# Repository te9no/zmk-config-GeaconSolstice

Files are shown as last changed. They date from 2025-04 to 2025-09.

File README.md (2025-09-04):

# キーボードについて
キーボード名：GeaconSolstice  
[roBa](https://github.com/kumamuk-git/roBa)や、[GRIN One](https://note.com/policium/n/nc7ceb56d11fe)にインスパイアされて設計したGeaconを、さらに発展させたオリジナルキーボードです。

## 謝辞
トラックボールケースはkepeoさんのデータを利用させていただきました。  
[Keyball Trackball Case (Test) by kepeo - Thingiverse](https://www.thingiverse.com/thing:6749719)  
トラックボール基板はkumaさんの設計したデータを利用させていただきました。  
[GitHub - kumamuk-git/roBa](https://github.com/kumamuk-git/roBa)  

## 特徴
・ZMKによる無線接続対応  
・60%分割Grin配列  
・トラックボール、OLED、アナログスティック搭載  

### US配列


### JIS配列


## 販売
たぶん[booth](https://te9no.booth.pm/)で販売  

## ビルドガイド
[here](https://github.com/te9no/zmk-config-GeaconSolstice/blob/main/docs%2Fbuildguide.md)

## ファームウェア
[Github](https://github.com/te9no/zmk-config-GeaconSolstice/tree/main/firmware)  

## 注意事項
リポバッテリーを不適切に取り扱うと発火等の危険性があります。  
接続時の極性の向きや、リード線の短絡、組み立てには十分ご注意下さい。  
またPCBやケースの角、ピンヘッダーなど鋭利な箇所が多数存在していますので、怪我しないようご注意下さい。  
マイコン裏のパッドはバッテリーに接続されてるため、短絡させないようご注意下さい。  
取り扱いの不備により発生した怪我、事故等の責任は負いかねます。

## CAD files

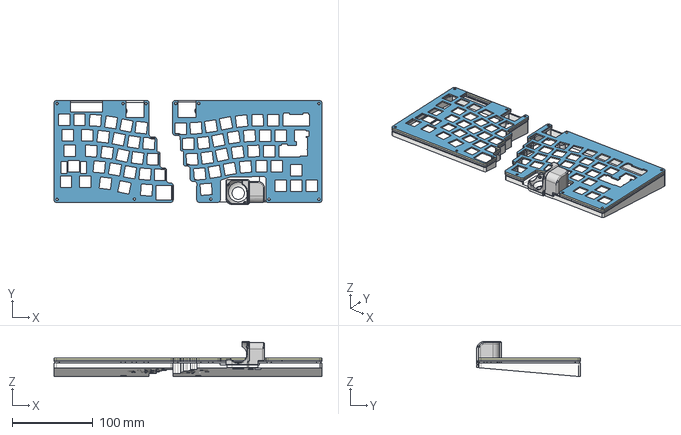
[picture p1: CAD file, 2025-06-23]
case/GeaconSolstice.step
331.8 x 128.9 x 43.7 mm

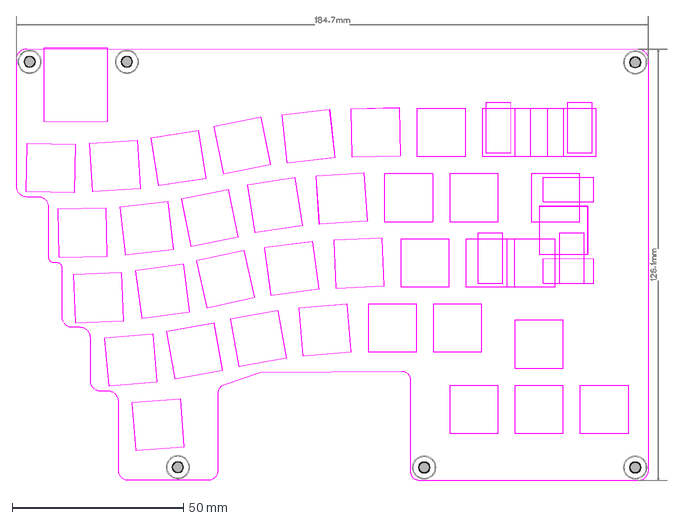
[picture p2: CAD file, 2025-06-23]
case/DXF_GeaconSolstice_R_top_2025-05-07_AutoCAD2007.dxf
190.3 x 135.9 mm

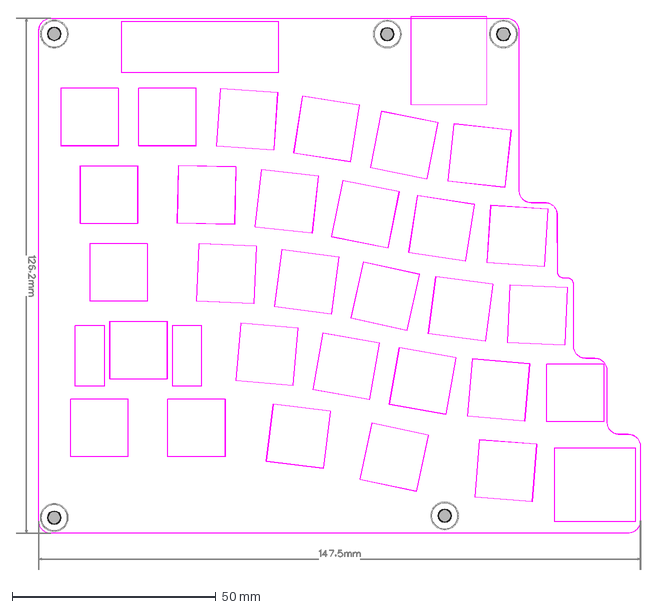
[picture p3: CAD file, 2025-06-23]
case/DXF_GeaconSolstice_L_top_2025-05-07_AutoCAD2007.dxf
153.2 x 135.6 mm

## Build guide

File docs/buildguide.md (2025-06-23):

# 🌞 GeaconSolstice 🌛 ビルドガイド

## 🚀 はじめに
このビルドガイドではGeaconSolsticeの組み立て手順を説明します。組み立ては約1-2時間程度で完了します。

## 📋 目次
1. [部品の確認](#部品確認)
2. [組み立て手順](#組み立て手順)
3. [ファームウェアの書き込み](#ファームウェアの書き込み)
4. [キーボードの使い方](#キーボードの使い方)

## 📦 部品確認
### 📥 付属品
|名前|数|備考|
|:-|:-|:-|
|メインPCB（右）|x1| |
|メインPCB（左）|x1| |
|Seeed Studio XIAO nRF52840|x2|メインPCBに取付済み|
|PMW3610用PCB|x1|メインPCBに取付済み|
|L字ピンヘッダー|x1|メインPCBに取付済み|
|バッテリー用ケーブル|x2|※無線化する場合のみ必要|
|スイッチプレート（右）|x1| |
|スイッチプレート（左）|x1| |
|ケース（右）|x1| |
|ケース（左）|x1| |
|ガスケット（右）|x1|MXのみ必要|
|ガスケット（左）|x1|MXのみ必要|
|リセットスイッチボタン|x2| |
|トラックボールケース|x1| |
|2mmセラミックボール|x3|トラックボールケースに圧入済み|
|OLED|x1|メインPCBに取付済み|
|アナログスティック|x1||
|M3x5mmネジ|x2| |
|M3x6mmネジ|x11| |

### 🛒 別途用意するもの
|名前|数|備考|
|:-|:-|:-|
|34mmボール|x1| |
|Cherry MX/Choc V2キースイッチ|x63～64|JIS配列の場合x64|
|Cherry MXキーソケット|x63～64|JIS配列の場合x64|
|PCBマウントスタビライザー|x2～3|Cherry MXの場合のみ、JIS配列の場合x2|
|キーキャップ| | |
|3.7V電池（Lipoバッテリー502030想定）|x2|※無線化する場合のみ|
|両面テープ|x2|バッテリー固定用|

### 🛠️ 必要な工具
|工具名|用途|備考|
|:-|:-|:-|
|はんだごて|はんだ付け作業|温度調節機能付きを推奨|
|はんだ|各種実装|Pb含有はんだ 0.8mm程度|
|ニッパー|リード線カット用| |
|精密ドライバー|ネジ止め用|M2、M3用|
|ピンセット|部品の取り扱い用| |

## 🔧 組み立て手順

### ⚡ スイッチソケット、スタビライザーの実装
1. PCBの印刷された向きに注意してソケットを置く
2. ソケットをはんだ付けする
3. はんだ付けが確実にされているか確認する
4. スタビライザーを取り付ける  
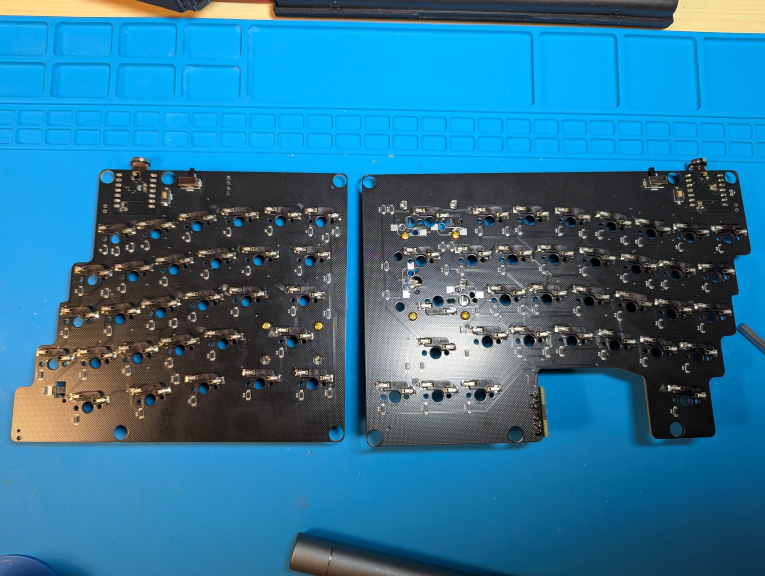
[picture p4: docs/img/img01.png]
  
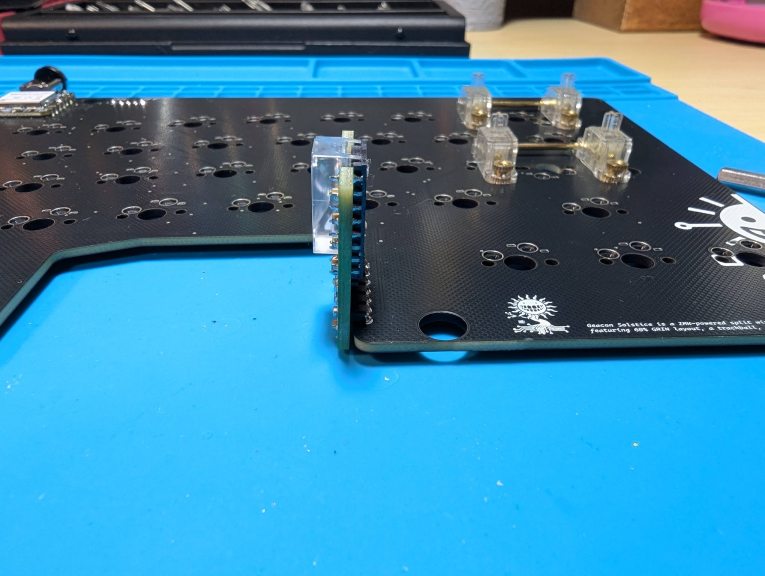
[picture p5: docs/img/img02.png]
  

### 📺 OLEDの実装
⚠️ **重要: ピンの向きを間違えると故障の原因となります**

1. OLEDモジュールのピン配列を確認
   - VCC
   - GND
   - SCL
   - SDA
2. PCB上の印字とピン配列を合わせて差し込む
3. 裏面からはんだ付けを行う
4. ピンの余分な部分をカット

### 🔋 バッテリーケーブルの実装
⚠️ **重要: 極性を間違えると故障の原因となります**

1. メイン基板を裏向きにする
2. バッテリーのパッドの極性を確認する
   - 上: +（VCC、赤）
   - 下: -（GND、黒）
3. ケーブルを差し込み、表からはんだ付けする
4. 余分なリード線をカットする
5. ケーブルをテープや接着剤でPCBに固定する（推奨） 
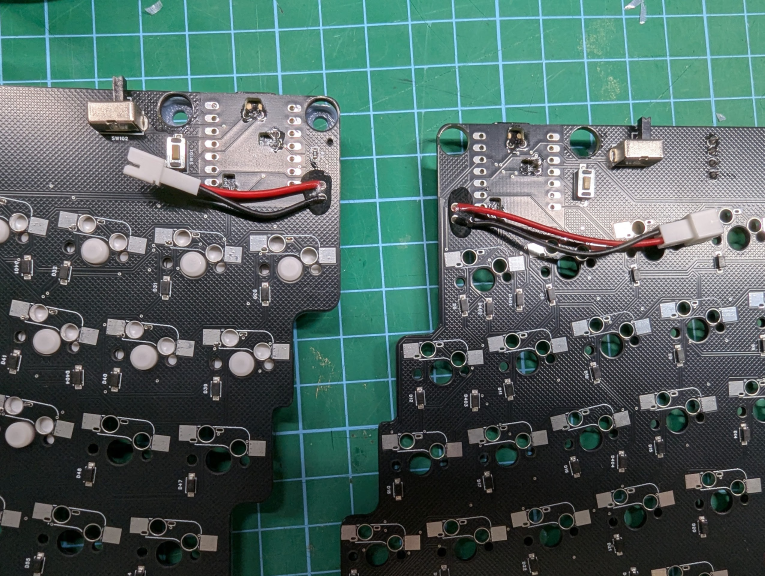
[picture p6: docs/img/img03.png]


⚠️ **注意**: PCB実装時にケーブルを挟まないよう注意してください

### 🔌 バッテリーの実装
ケース左上の空間にバッテリーを両面テープなどで固定する。  
バッテリーケーブルとバッテリーを接続する。（赤線と赤線、黒線と黒線がつながるようにすること。）  
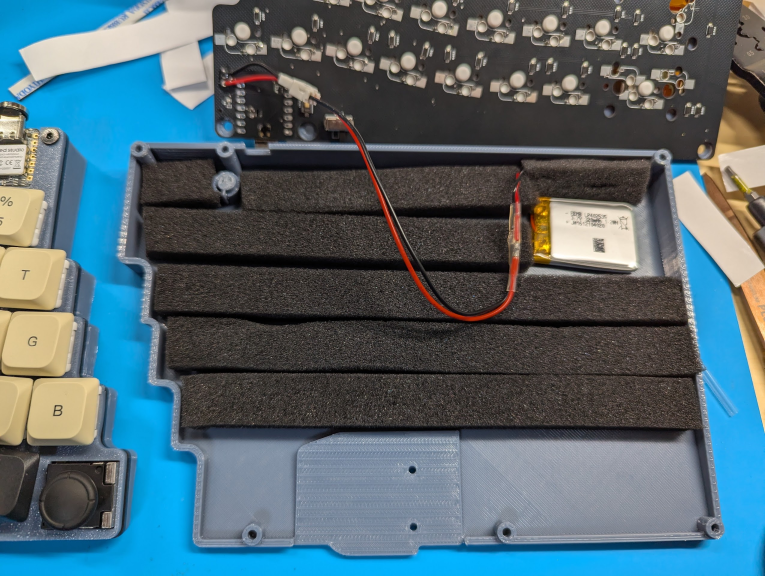
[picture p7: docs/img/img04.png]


### 🕹️ アナログスティックの実装
1. FFCコネクタの爪を持ち上げて開放状態にする  
■閉じた状態  
  
■開いた状態  
  

2. アナログスティックのネジ穴の突起を切り取る  
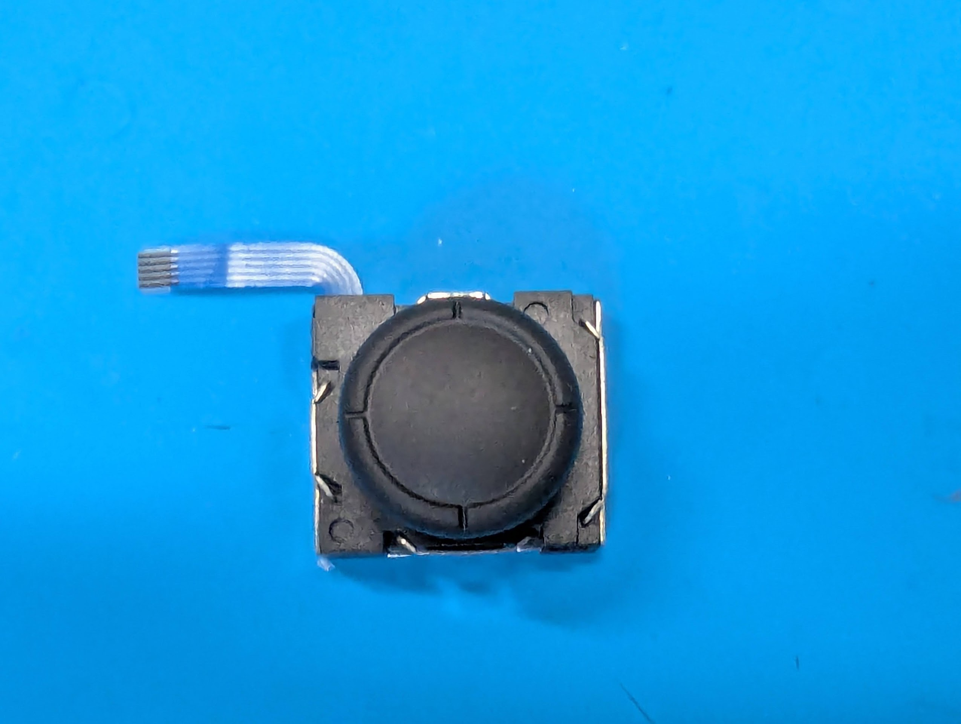
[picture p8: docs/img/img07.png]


3. FFCケーブルの向きに注意して、コネクタに差し込む  


4. FFCコネクタの爪を下げて閉じた状態にする  


5. アナログスティックの裏面に両面テープを張って基板に固定する

### ⌨️ スイッチプレートの組み立て
1. MXスイッチを使用する場合はガスケットとPCBとスイッチプレートの間に挟む  
⚠️ **注意**: choc v2スイッチを使用する場合は不要です。  

2. スイッチプレートとメインPCBを重ねてスイッチを挿していく。  
⚠️ **注意**: スイッチの足が曲がらないように注意して挿入してください
⚠️ **注意**: スイッチプレートはプラスチック製のため傷がつきやすいため、取り外しの際はご注意ください

### 📦 ケースの組み立て
1. リセットスイッチをケース内側から差し込む。（吹き飛びやすいので注意）  
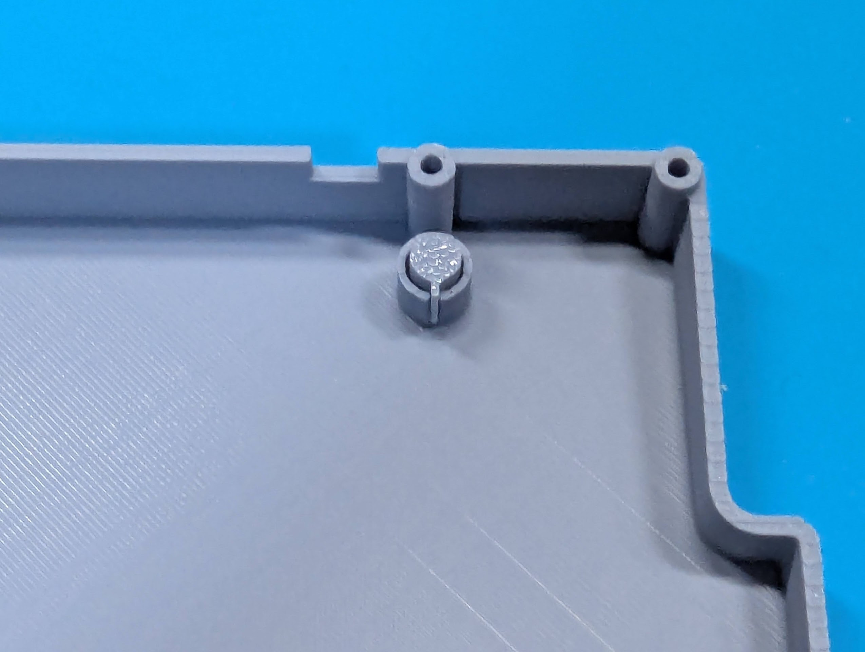
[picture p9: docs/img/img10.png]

2. メインPCBをケースに取り付ける。この時、バッテリーケーブルがPCBのネジ穴とケースの固定用突起などに挟まれないように注意すること。  
3. M3ネジでPCBをケースに固定する。  

### 🔮 トラックボールケースの実装
トラックボールケースを差し込み、裏からM2ネジで固定する。  

## 💾 ファームウェアの書き込み
1. USBケーブルでPCに接続する。  
2. 裏面のリセットスイッチを素早く2回クリックするとUSBドライブとしてマウントされる。  
3. UF2ファイルをドラッグ＆ドロップするとファームウェアの書き込みが始まる。  
4. 完了すると自動的に切断され、使用できる状態となる。  

## 🌲 完成！
これで完成です。出来上がったキーボードの写真を各種SNSやビルドログとして投稿いただけると、私が泣いて喜びます。  
私の最高到達点としての、GeaconSolsticeをお楽しみください。

## 💫 キーボードの使い方

### 🎯 レイヤー機能の概要
|レイヤー番号|名称|機能概要|
|:-|:--|:--|
|0|USレイヤー|標準レイヤー|
|1|疑似JISレイヤー|🇯🇵日本語入力用レイヤー|
|2|Functionレイヤー|⚙️ファンクションキー|
|3|マウスレイヤー|🖱️トラックボール操作|
|4|スクロールレイヤー|📜スクロール操作|
|5|BTレイヤー|📶無線接続設定|

### 🇯🇵 JISレイヤー機能
- tabキー長押しでレイヤー1（疑似JISレイヤー）を有効/無効を切り替える。  
- レイヤー1は日本語配列として認識しているキーボードで英語配列の入力ができる。  
  （例：日本語配列として認識しているPCで、レイヤー1を有効にしてSHIFT+2→＠を入力） 

### 🖱️ マウスレイヤー機能
以下のマウス入力が可能となる。
|キー|機能|
|:-|:-|
|「.」キー|左クリック|
|「/」キー|中央クリック|
|「右SHIFT」キー|右クリック|

### 📶 接続プロファイル切り替え機能
- 「＼」キーを押している間レイヤー5が有効になり、同時に数字1~5を押すことで接続プロファイルを切り替える。  
- レイヤー5で「`」キー→現在の接続プロファイルを消去する。tabキー→接続プロファイルを全て消去する。  

## ℹ️ その他
### 🔌 電源スイッチ
電源スイッチは左側でON、右側でOFFとなる。

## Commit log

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2025-03-05 Refactor GeaconSolstice_L overlay to improve I2C controller compatibility and enhance OLED display configuration
2025-03-05 Update GeaconSolstice keymap dimensions and enable battery reporting features
2025-03-08 Fix I2C SDA pin selection in GeaconSolstice pinctrl_L configuration
2025-03-08 Add clock frequency setting and pull-up resistors in GeaconSolstice_L overlay
2025-03-08 Remove unused SPI configuration from GeaconSolstice_L overlay
2025-03-09 Disable xiao_serial and remove unnecessary pull-up resistor comment in GeaconSolstice_L overlay
2025-03-09 Update SSD1306 I2C address in GeaconSolstice_L overlay
2025-03-09 Update SSD1306 I2C address to 0x3c and add pull-up resistors in GeaconSolstice_L configuration
2025-03-09 Update SSD1306 I2C address to 0x3d and remove LVGL configuration in GeaconSolstice_L
2025-03-09 Add dedicated work queue for display and update SSD1306 I2C address to 0x3c
2025-03-09 Add pull-up resistors to GeaconSolstice_L overlay configuration
2025-03-09 Add initialization delay for external power in GeaconSolstice_L overlay
2025-03-09 Fix formatting for external power initialization delay in GeaconSolstice_L overlay
2025-03-09 Add I2C configuration and update external power initialization delay in GeaconSolstice_L
2025-03-09 Update I2C configuration for display in GeaconSolstice_L overlay
2025-03-09 Remove pull-up resistor configuration from GeaconSolstice_L overlay
2025-03-09 Add I2C configuration and display settings for SSD1306 in GeaconSolstice_L overlay
2025-03-09 Update compatible string for I2C controller in GeaconSolstice_L overlay
2025-03-09 Fix I2C controller compatibility and update pinctrl settings in GeaconSolstice_L overlay
2025-03-09 Update pinctrl settings to use I2C identifiers in GeaconSolstice_L overlay
2025-03-09 Update I2C configuration to use TWIM identifiers in GeaconSolstice_L overlay
2025-03-09 Update I2C controller compatibility to use Nordic TWI in GeaconSolstice_L overlay
2025-03-09 Rename I2C display node to xiao_i2c in GeaconSolstice_L overlay
2025-03-09 Remove unnecessary pinctrl settings and update I2C controller compatibility in GeaconSolstice_L overlay
2025-03-09 Remove I2C display node activation in GeaconSolstice_L overlay
2025-03-09 Refactor I2C display node configuration in GeaconSolstice_L overlay
2025-03-09 Remove redundant I2C pinctrl configuration from Solstice_L overlay and clean up pinctrl_L.dtsi
2025-03-25 Add GeaconSolstice device tree configuration for US and JIS layouts
2025-03-25 Update GeaconSolstice device tree to use US layout configuration
2025-03-25 Remove GeaconSolstice device tree configuration for US and JIS layouts
2025-03-25 Add default transform to US and JIS layout configurations in GeaconSolstice device tree
2025-03-25 Add kscan configuration to US and JIS layout in GeaconSolstice device tree
2025-03-25 Update layout_US positions in GeaconSolstice device tree
2025-03-25 Update key mapping in GeaconSolstice device tree for improved layout
2025-03-26 Update keymap bindings in GeaconSolstice device tree for enhanced functionality
2025-03-27 Disable dongle battery display in Solstice_L configuration
2025-03-27 Remove RGB LED widget configuration from Solstice keymap and Solstice_L configuration
2025-03-27 Add RGB LED configuration to Solstice keymap
2025-03-27 Add configuration for dongle battery reporting in Solstice_L
2025-03-29 Update Solstice_L configuration to switch from dongle_display to nice_oled and adjust related settings
2025-03-29 Add I2C support and configure analog input for Solstice_L board
2025-03-29 Enable ADC and analog input configuration for Solstice_L board
2025-03-29 Add zmk-analog-input-driver to west.yml manifest
2025-03-29 Add analog input listener configuration for Solstice_L board
2025-03-29 Update I2C pin configuration in Solstice_L pinctrl
2025-03-29 Update I2C compatibility in Solstice_L overlay
2025-03-29 Update I2C compatibility and pin configuration in Solstice_L overlay
2025-03-29 Update GPIO pin configuration in Solstice_L overlay
2025-03-29 Update I2C pin configuration in Solstice pinctrl layer
2025-03-29 Enable widget layer and battery status display in Solstice_L configuration
2025-04-16 Refactor Solstice configuration: remove physical layouts and add LED definitions
2025-04-17 fix adc
2025-04-17 fix int pin
2025-04-18 Add keyboard name configuration and input relay support for GeaconSolstice boards
2025-04-18 Fix device reference in input relay configuration for trackball
2025-04-18 Refactor trackball input configuration and disable unused input relay
2025-04-18 Disable trackball and UART configurations in Solstice overlays
2025-04-20 Refactor Solstice keymap and configuration files to improve layer labeling and adjust ADC settings
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2025-04-23 Update Solstice configuration files to comment out unused battery level settings and adjust keymap array formatting
2025-04-23 Add JIS keymap configuration and update build settings for Solstice boards
2025-04-23 [Draw] Add JIS keymap configuration and update build settings for Solstice boards
2025-04-30 Add split configuration and Bluetooth parameters for Solstice boards
2025-05-06 Enable battery level proxy and fetching for split BLE central in Solstice configurations
2025-05-07 add case
    [GeaconSolstice.step]
2025-05-07 fix DXF
    [DXF_GeaconSolstice_L_top_2025-05-07_AutoCAD2007.dxf, DXF_GeaconSolstice_R_top_2025-05-07_AutoCAD2007.dxf]
2025-06-23 layout shift
    [DXF_GeaconSolstice_L_top_2025-05-07_AutoCAD2007.dxf, DXF_GeaconSolstice_R_top_2025-05-07_AutoCAD2007.dxf, GeaconSolstice.step]
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2025-09-05 キー マップのラベルを display-name に変更
